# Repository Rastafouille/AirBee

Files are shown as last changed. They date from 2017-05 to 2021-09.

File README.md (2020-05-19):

# AirBee
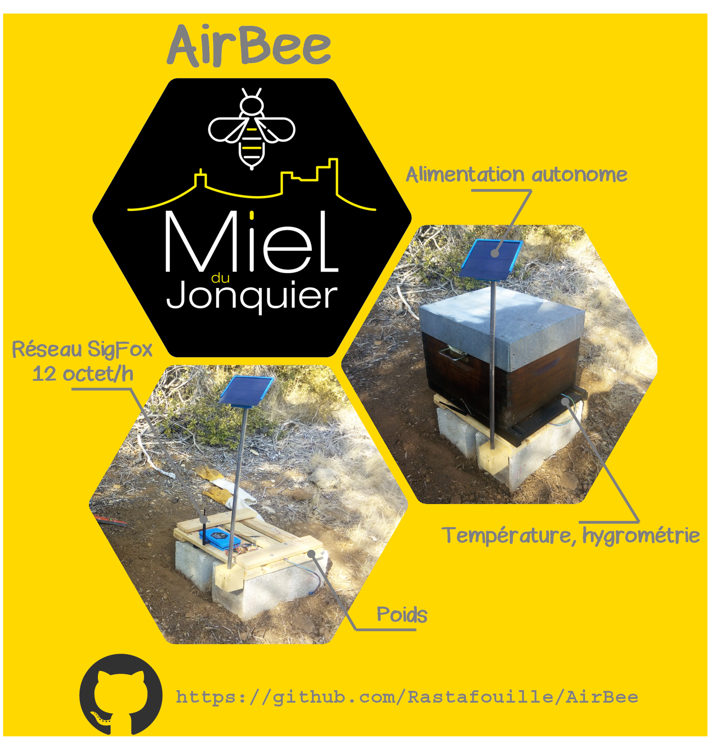
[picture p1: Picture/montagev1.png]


L'idée est de transmettre toutes les données suivantes :
- température dans la ruche -- fait
- humidité dans la ruche -- fait
- masse de la ruche -- fait
- nombre d'abeilles entrées -- pas fait
- nombre d'abeille sortie -- pas fait
- tension de la batterie -- fait
Via un système 100% autonome en énergie et communication

Il y a eu 2 versions v1 et v2, je vous laisse les 2 pour voir ce qui n'a pas/mal fonctionné sur la premiere et les améliorations apportées.

Le système est maintenant abouti et fonctionnel.

## Coté alimentation : 
- Une lipo 5Ah <http://www.cdiscount.com/telephonie/batteries-telephone/easyacc-batterie-externe-5000mah-ultra-slim-charge/f-14487-eas0700686513077.html> (33€)
- Panneau solaire 3W <https://www.digikey.fr/product-detail/fr/seeed-technology-co-ltd/313070001/1597-1414-ND/5488054> (12USD)
- lipoRider <https://www.seeedstudio.com/Lipo-Rider-v1.3-p-2403.html> (9.5USD)

3 fils partent du module d'alim vers la carte (vcc,gnd,Vbat)




Cette partie n'a pas évoluée entre les 2 versions

## Coté intelligence :
- Carte ucontrolleur Arduino nano (2€) <https://fr.aliexpress.com/item/Freeshipping-Nano-3-0-controller-compatible-for-arduino-nano-CH340-USB-driver-NO-CABLE/32242060255.html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>

## Coté communication :
- Kit Carte Breakout Sigfox BRKWS01 + Antenne +fdp TTC + un an abonnement <https://yadom.fr/carte-breakout-sfm10r1.html> (26€)
ou que le module <https://yadom.fr/reseaux-iot/sigfox/pack-10-modules-wisol-sfm10r1-pour-le-reseau-sigfox.html> (4€) mais il faut payer l'abonnement, sauf que l'on ne peut pas en prendre a l'unit", c'est par 10 pour plus de 220€ par an...

## Coté Capteur :
- pour avoir l'heure RTC  <https://www.adafruit.com/product/3296> (7.5USD) -- pas indispensable, supprimé sur la v2.
- Compteur I/O abeilles : projet BeeCounter2 (25USD) <http://www.instructables.com/id/Honey-Bee-Counter-II/> pas fait finalement.
- Capteur température humidité SHT11 (35USD) (2€ sur Aliexpress) <https://www.adafruit.com/product/246>. Une autre version avec DHT22 marche trés bien aussi.
- v1 : Capteur poids X4 + Load Cell Amplifier - HX711 (5€) <https://fr.aliexpress.com/item/FREE-SHIPPING-20pcs-lot-Experiments-body-scale-wholesale-human-scale-load-cell-sensor-resistance-strain-50kg/32271599811.html> et <https://fr.aliexpress.com/item/1PCS-HX711-Weighing-Sensor-Dual-Channel-24-Bit-Precision-A-D-Module-Pressure-Sensor-for-Arduino/32653087154.html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> 
Impossible d'avoir une valeur stable et fiable.... du coup mieux en v2



  v2 : Un seul capteur 100kg + Load Cell Amplifier - HX711, bcp plus précis et sans dérive (17€) <https://fr.aliexpress.com/item/100kg-120kg-parallel-beam-type-load-cell-for-counting-scale-balance-TAL201/32616652058.html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>

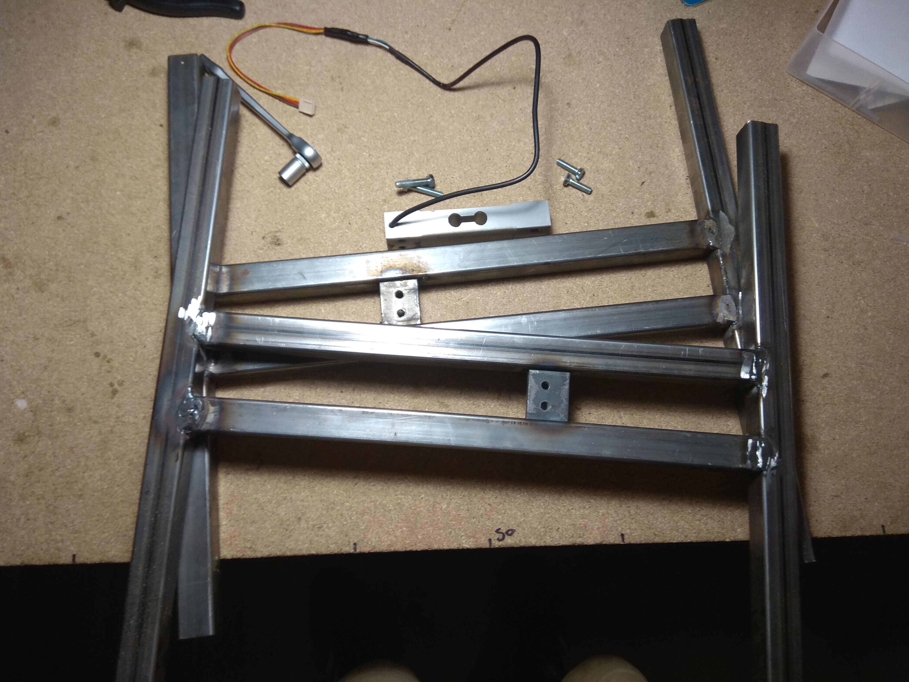
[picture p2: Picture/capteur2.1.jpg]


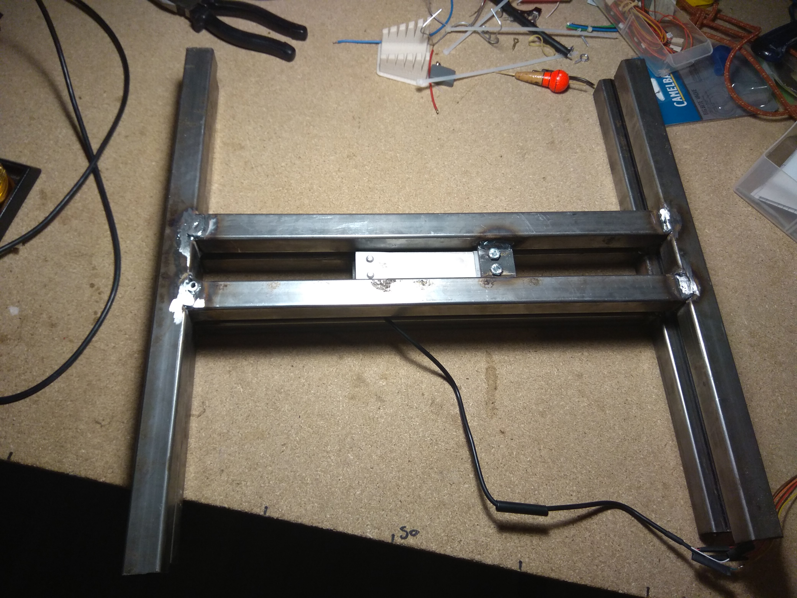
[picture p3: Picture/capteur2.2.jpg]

  
## PCB

- v1
a la main !


- v2

Fait sur Easy EDA <https://easyeda.com/rastafouille/airbeev2-2> fabriqué maison dans un premier temps mais commandé chez jlcpcb ou pcbway pour quelques €

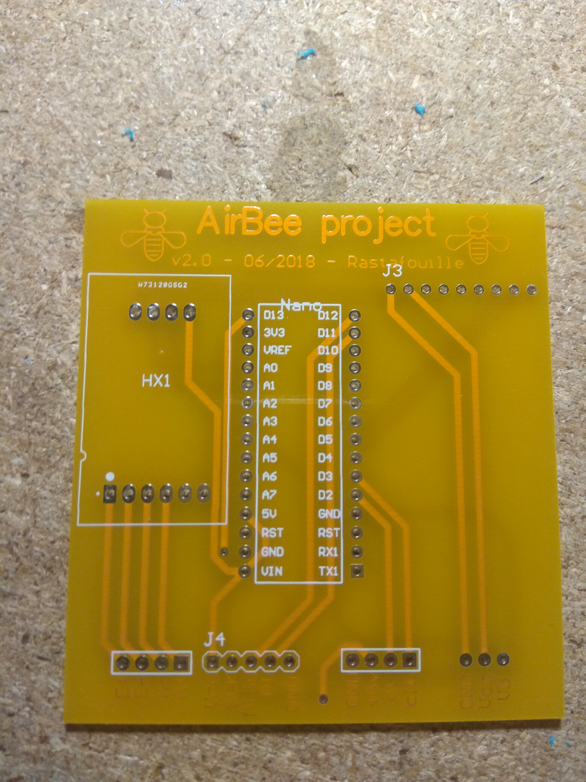
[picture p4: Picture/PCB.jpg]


## Packaging

- Toutes les pièces en impression 3D pour la v1, les fichiers sont dans le dossier CAD. 
pour la v2 seul le module d'alimentation est en 3D print, pour le reste si dessous, bien mieux en finition et étanchéité.

- Connecteurs commandés pour la V2 (8€): <https://www.aliexpress.com/snapshot/0.html?productId=32761320961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>

- Boites commandées pour la V2 (6€): <https://fr.aliexpress.com/item/1-Pc-tanche-Bo-tier-En-Plastique-Bo-te-lectronique-Projet-Instrument-Cas-lectrique-Bo-te/32862281438.html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>

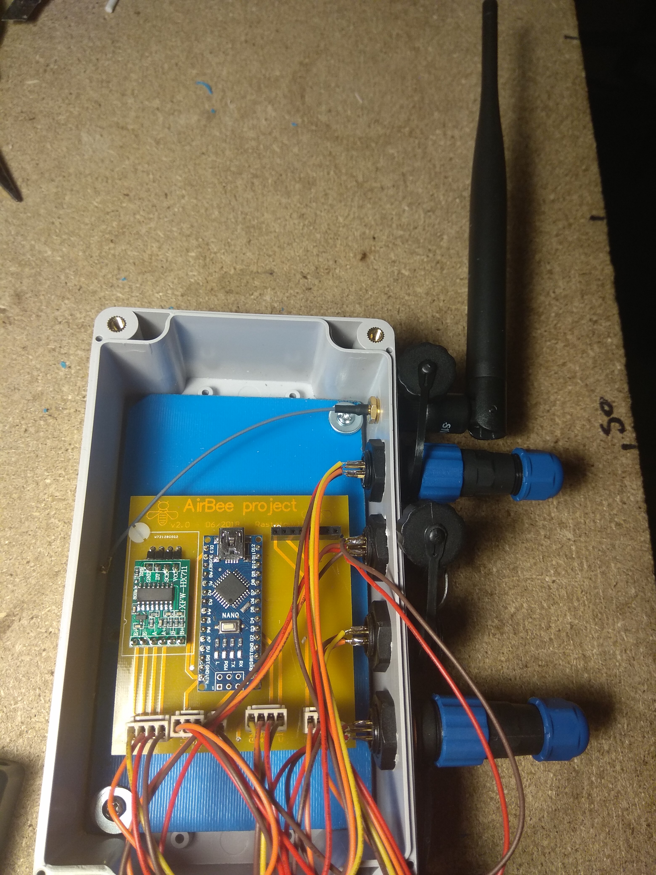
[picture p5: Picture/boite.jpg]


## Vue d'ensemble 

- V1 08/10/2017 



- V2 

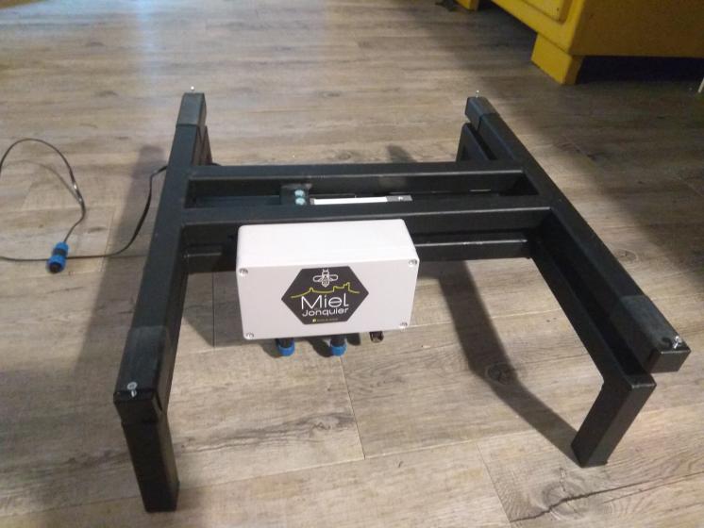
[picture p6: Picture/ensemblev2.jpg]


## Fonctionnement
L'Arduino centralise les données est les envoie au backend sigfox. On a droit à 140 messages de 12 Octets par jour, ca passe juste sans optimisation.

Payload : 
	
	ID::uint:8 Temp::int:16:little-endian Hum::uint:16:little-endian Poids::uint:16:little-endian IN::uint:16:little-endian OUT::uint:16:little-endian Vbat::uint:8

Sigfox renvoie les données via des CallBacks vers serveur perso (php-->json) et backend web (app.we-sens.com). je n'ai rien fait coté web j'utilise le site hebergeur d'un copain (app.we-sens.com) qui m'affiche les données.

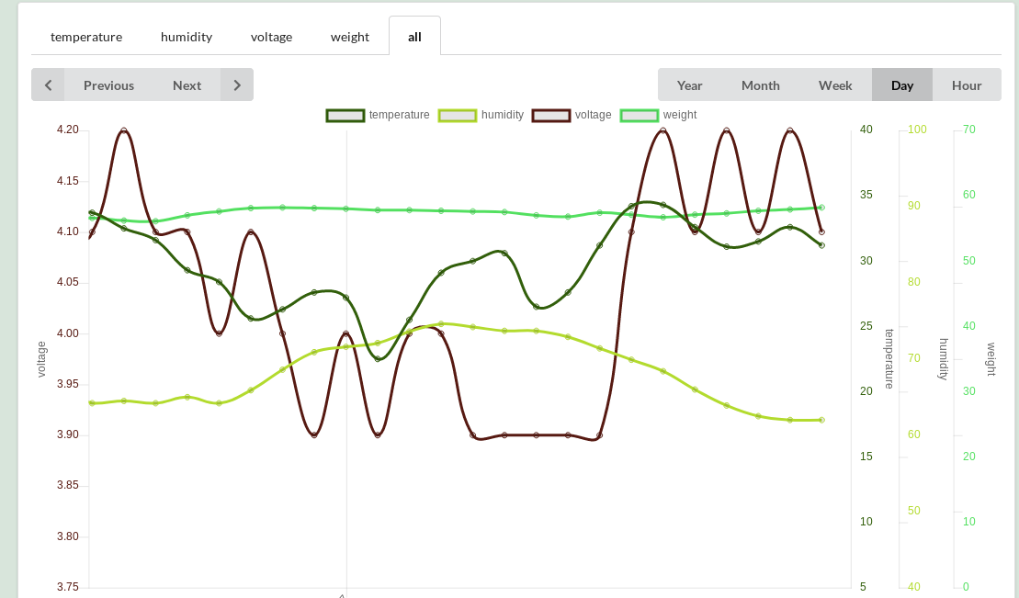
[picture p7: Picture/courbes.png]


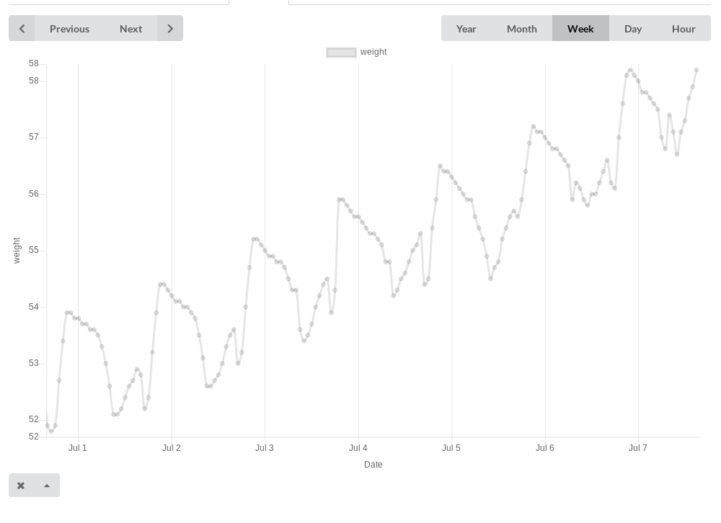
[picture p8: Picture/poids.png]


# Release
- v2 : suppression du RTC / changement capteur de poids et plateau / carte electronique dédiée faite maison

- V2.1: boite / connecteur / PCB pro / rafraichissement toutes les 15 min

- V2.2 04/2020 : soudage pieds au plateau / DHT22 car SHT11 plus dispo / module sigfox en 3.3v / passage de circuit maker à easyEDA

# Perspectives
- Rajouter le compteur d'abeilles

- Rajouter une station météo mais les données capteurs humudité+température+tension batterie (ensoleillement) peuvent suffires.

- Peut etre créer un reseau Xbee local sur 5 ruches pour un seul module Sigfox (si utile d'avoir plusieurs ruches connectées dans le même rucher?)

- optimiser l'energie pour passer en pile lithium 3.3V et se passer du panneau solaire.

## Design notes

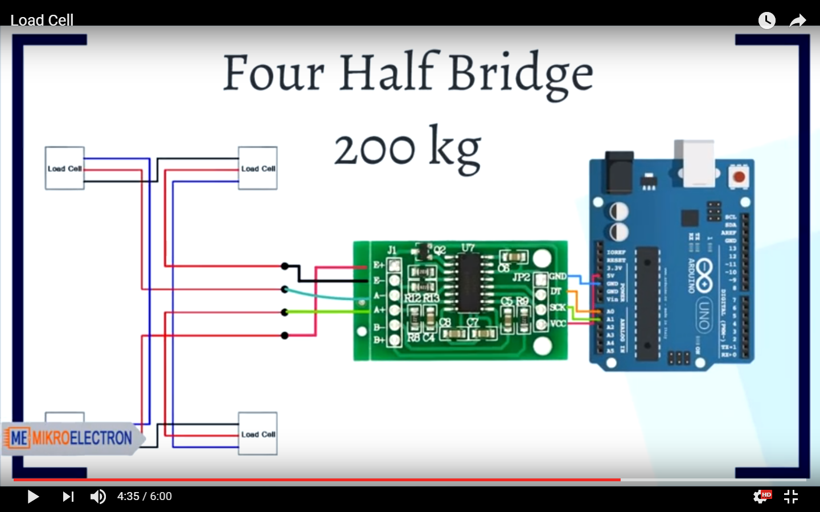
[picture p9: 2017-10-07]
vrac/loadcell.png

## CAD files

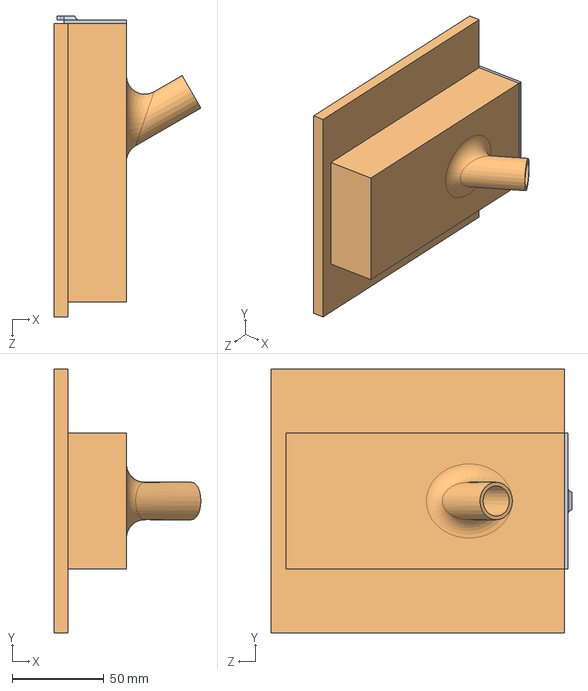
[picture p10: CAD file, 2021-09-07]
CAD/Assemblage1.SLDASM
80.1 x 144.0 x 164.0 mm
boitier_solaire_couv_v2
boitier_solaire_v2

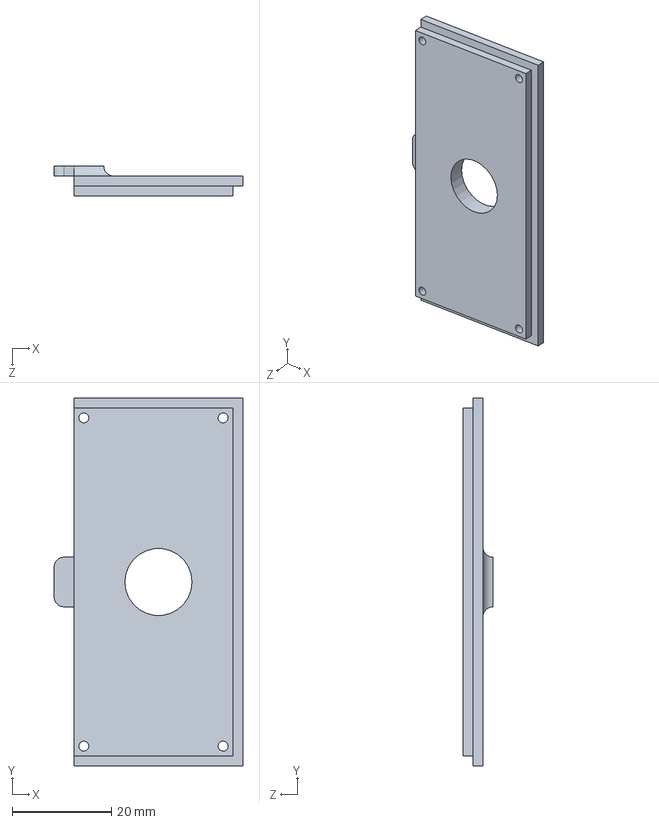
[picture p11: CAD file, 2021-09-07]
CAD/boitier_solaire_couv_v2.SLDPRT
38.0 x 74.0 x 6.00 mm

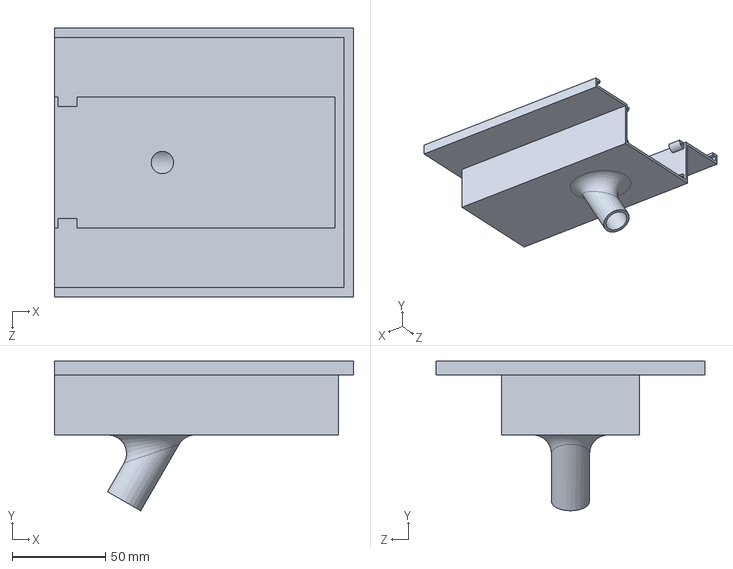
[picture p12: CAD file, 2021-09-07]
CAD/boitier_solaire_v2.SLDPRT
160.0 x 80.1 x 144.0 mm

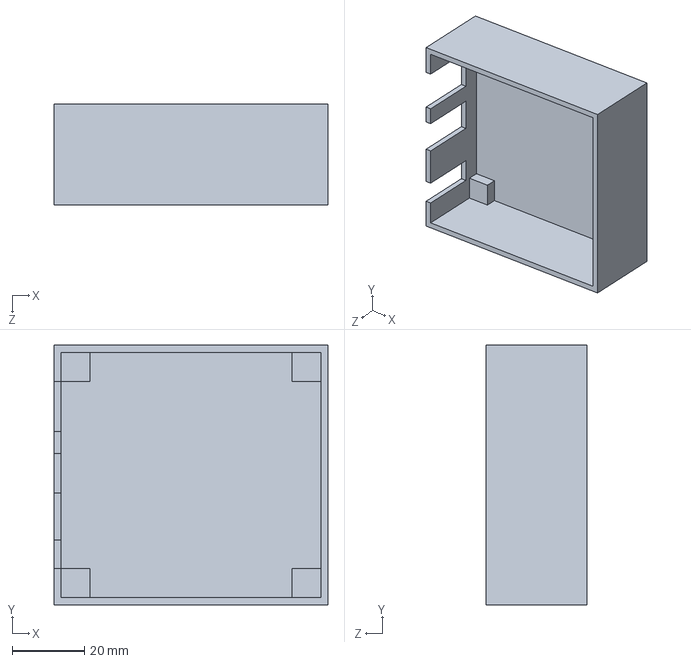
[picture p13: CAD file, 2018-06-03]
CAD/boite_electV2.SLDPRT
76.0 x 72.0 x 28.0 mm

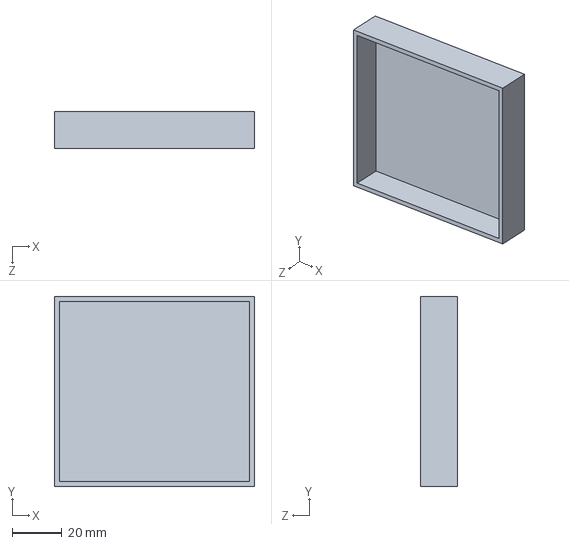
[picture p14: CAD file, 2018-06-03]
CAD/boite_elect_couvV2.SLDPRT
80.5 x 76.5 x 15.0 mm

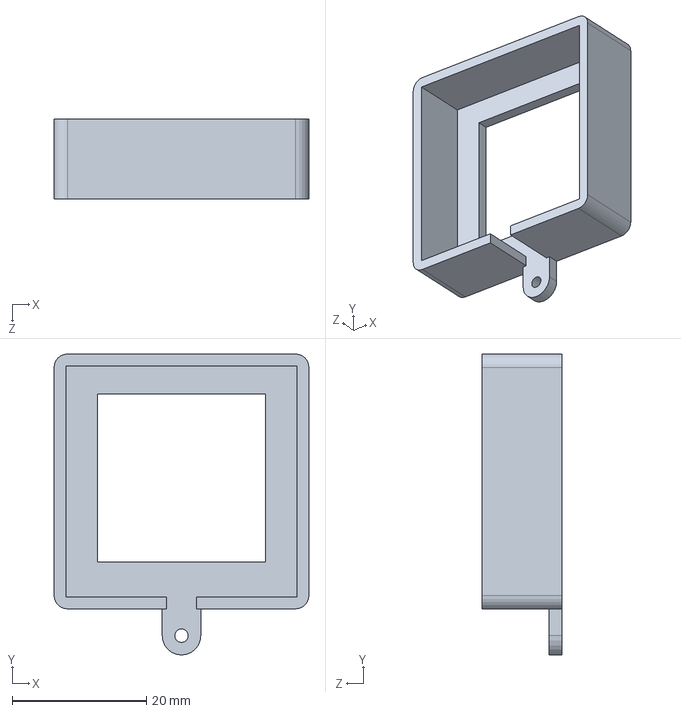
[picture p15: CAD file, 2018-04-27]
CAD/base _load.SLDPRT
38.0 x 44.9 x 12.0 mm

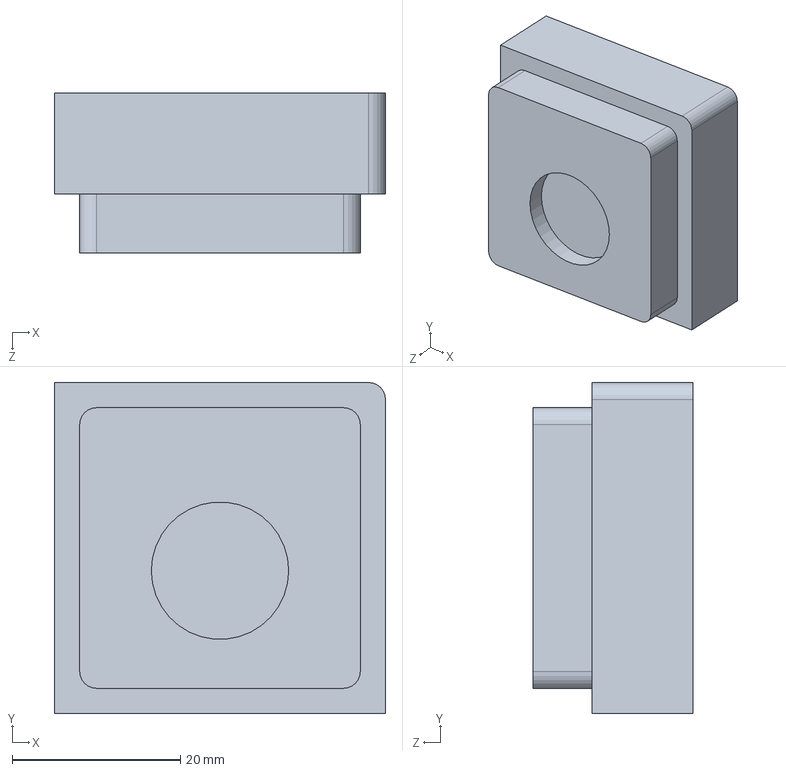
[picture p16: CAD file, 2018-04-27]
CAD/capot_load.SLDPRT
39.4 x 39.4 x 19.0 mm

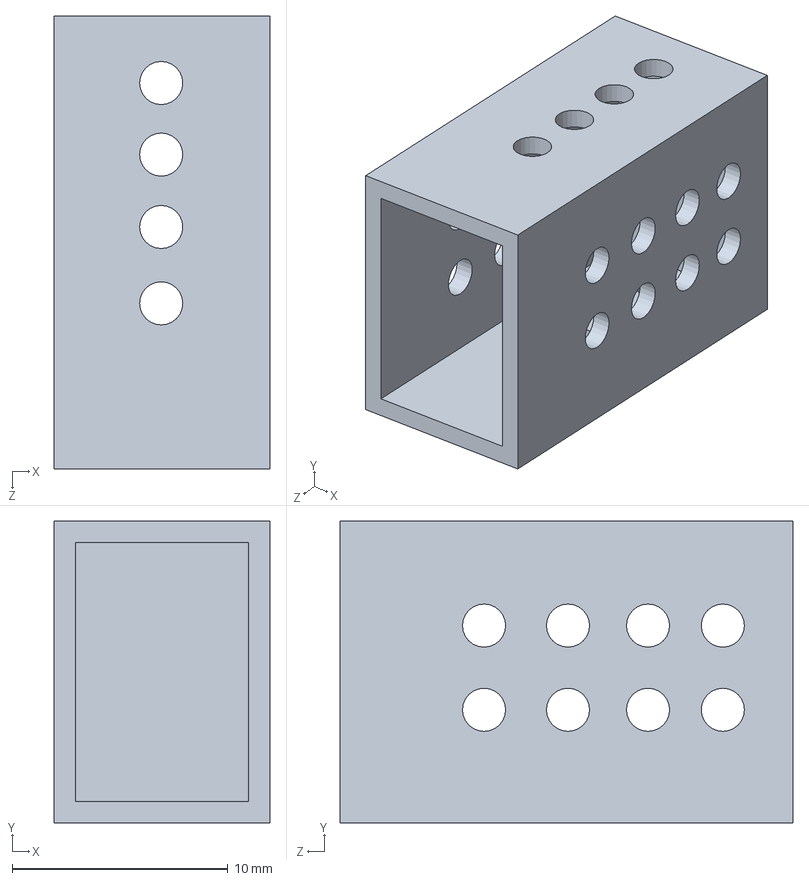
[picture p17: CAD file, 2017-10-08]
CAD/boite_temp.SLDPRT
10.0 x 14.0 x 21.0 mm

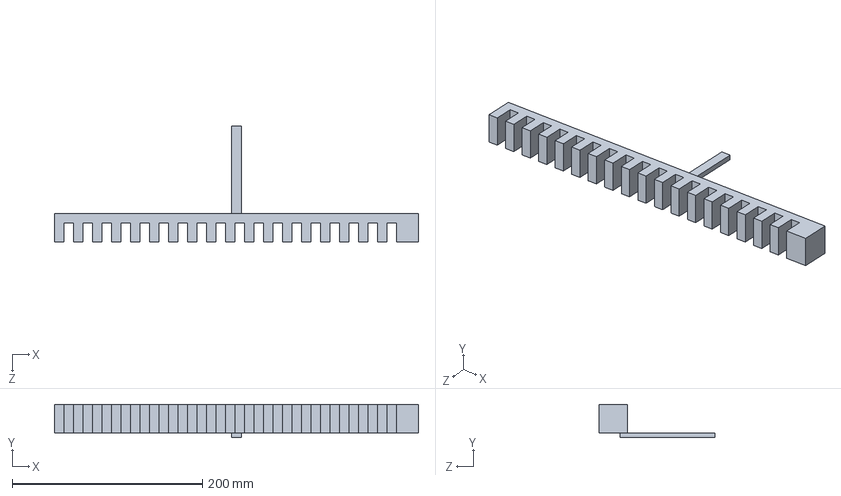
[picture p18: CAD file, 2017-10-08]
CAD/Porte.SLDPRT
383.0 x 35.0 x 121.8 mm

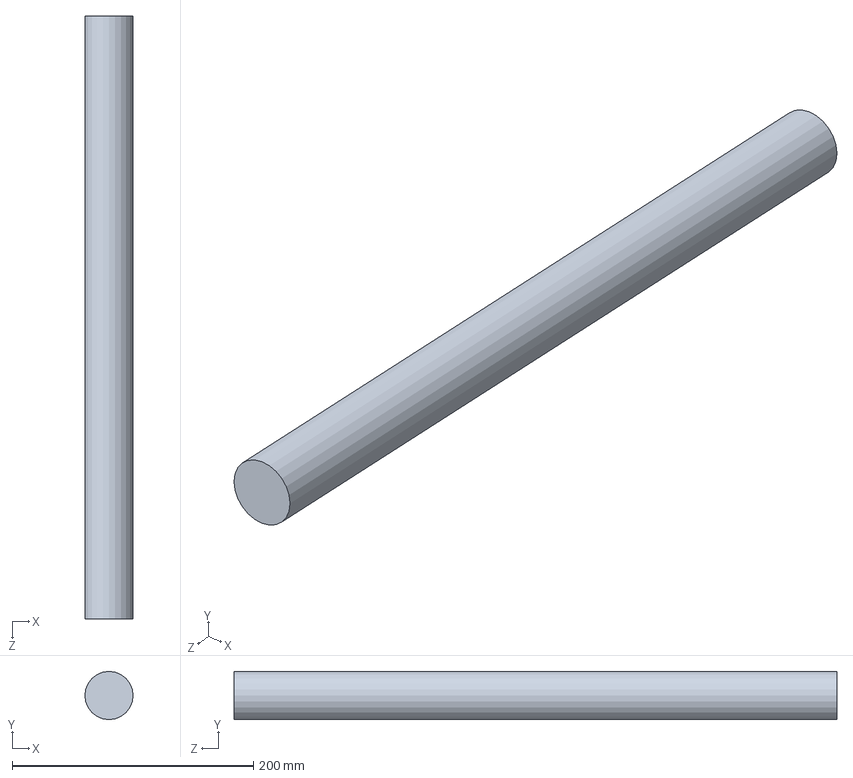
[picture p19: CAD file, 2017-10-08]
CAD/boitier_solaire_tube.SLDPRT
40.0 x 40.0 x 500.0 mm

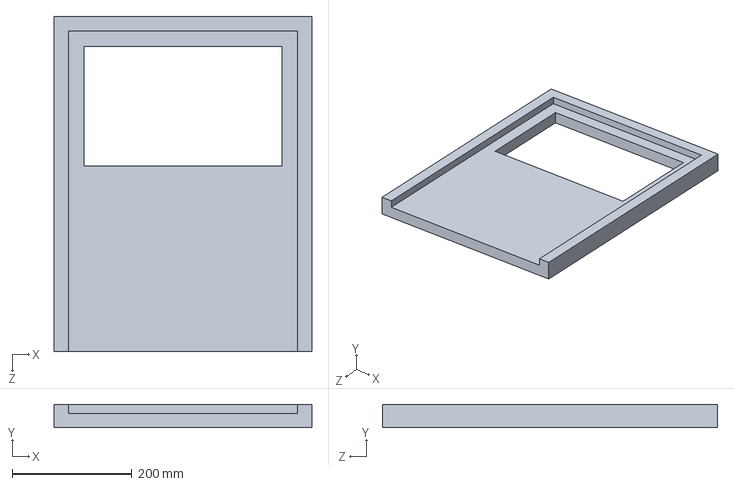
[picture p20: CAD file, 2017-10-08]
CAD/PlateauDadant.SLDPRT
431.0 x 39.0 x 560.0 mm

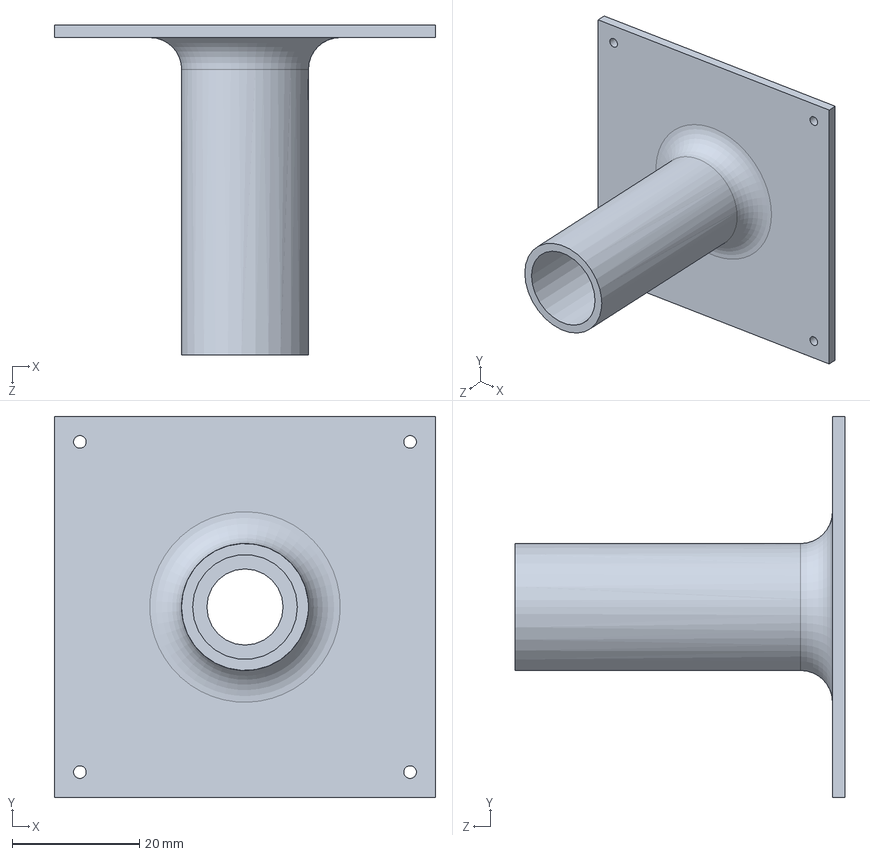
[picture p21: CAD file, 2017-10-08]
CAD/boitier_solaire_support.SLDPRT
60.0 x 60.0 x 52.0 mm

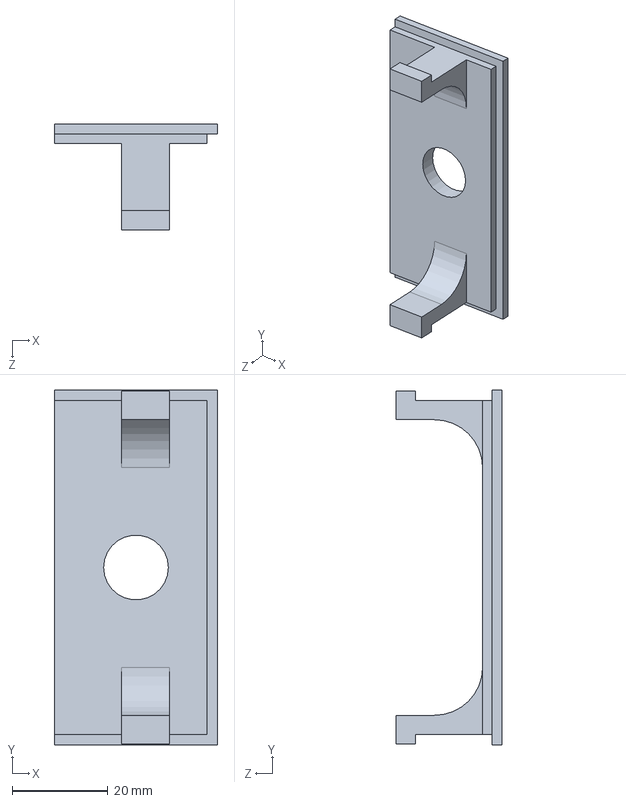
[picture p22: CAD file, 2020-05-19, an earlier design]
CAD/boitier_solaire_couv.SLDPRT
34.0 x 74.0 x 22.0 mm

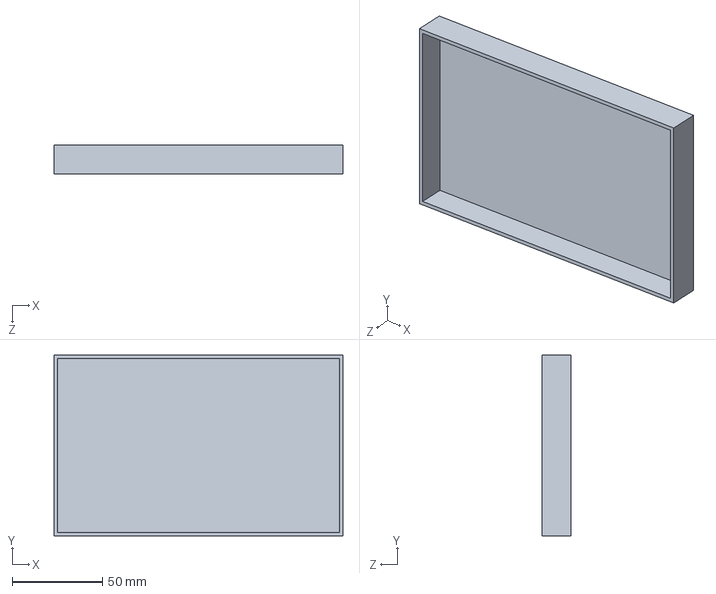
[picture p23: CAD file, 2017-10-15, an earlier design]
CAD/boite_elect_couv.SLDPRT
160.5 x 100.5 x 16.0 mm

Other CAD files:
CAD/boitier_solaire.SLDPRT
CAD/boite_elect.SLDPRT
CAD/base _load.STL
CAD/boite_elect.STL
CAD/boite_electV2.STL
CAD/boite_elect_couv.STL
CAD/boite_elect_couvV2.STL
CAD/boite_temp.STL
CAD/boitier_solaire.STL
CAD/boitier_solaire_couv.STL
CAD/boitier_solaire_couv_v2.STL
CAD/boitier_solaire_support.STL
CAD/boitier_solaire_v2.STL

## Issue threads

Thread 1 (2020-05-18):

echange sur le projet

guigui91, 2020-05-18:
Super votre projet. Ou peut on echanger avec vous?

Rastafouille, 2020-05-18:
bonjour, bien-sûr avec plaisir.

guigui91, 2020-05-18:
avez vous un email ou par ce biais la?

Rastafouille, 2020-05-18:
sur gît c'est très bien, que voulez vs savoir?

guigui91, 2020-05-18:
je me lance dans l'apiculture, je viens d'acheter deux ruches et votre projet me parait vraiement tres bien. j'ai bien compris la partie alimentation avec le panneau solaire la batterie et le module de chargement. Pour la partie de la balance vous avez un capteur et un amplificateur. Je repere bien sur le schema l'amplificateur ainsi que le nano par contre je ne vois pas le capteur d'humidité et temperature sht11 (d'ailleurs il n'a plus l'air d'exister en vente) ou est il branché? l'arrive du courant doit se faire dans un des connecteurs etanches mais a quoi servent les 3 autres?

Rastafouille, 2020-05-19:
Bonjour, le sht11 est branché sur l'arduino, je vais mettre le schéma a jour directement sur Git dans la semaine ce sera plus facile. pour les connecteurs il y a lalim, le capteur humidité température, le compteur d'abeilles (pas utilisé) et le capteur de poids.

Rastafouille, 2020-05-19:
si plus de sht11 on peut utiliser un DHT22, jai le code a jour pour ce capteur,
https://fr.aliexpress.com/item/32884816378.html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,searchweb201602_,searchweb201603_

guigui91, 2020-05-19:
ok j'utilise ce capteur aussi dans un autre projet et donc c'est ce capteur entre autre qui est dans un des connecteurs etanches? le plastique ne gene pas dans le calcul?

Rastafouille, 2020-05-19:
le capteur est a lextérieur au bout d'un cable pour le mettre ou on veut, avant je mettais dans la ruche mais ca ne m'apportait rien donc maintenant je ne mets dessous. Du coup il est relié a l'arduino via un connecteur étanche. le calcul de quoi? l'arduino interroge le capteur qui lui donne la température et l'humidité, il n'y a rien a calculer.

Rastafouille, 2020-05-19:
dans le schema que tu as, il y a une erreur, le module sigfox doit etre alimenté en 3.3v pas en 5.5v du coup il faut rajouter un pont diviseur avec 2 resistances.

Rastafouille, 2020-05-19:
jai mis a jour le schema

guigui91, 2020-05-19:
bon il faut que je commande tout lol ali express ils sont pas pressé lol

guigui91, 2020-05-19:
je pensais qu'on ne pouvis pas mettre le capteur a l'exterieur je pensais pas qu'il resistait au intemperies, du coup il donne la temperature  en dessous la ruche?la capteur de poids il ne depasse pas du support je ne vois pas le capteur de poids sur le support

Rastafouille, 2020-05-20:
j'ai des pièces en rabe, tu habites où?

Rastafouille, 2020-05-20:
il est au bout d'un fil tu le mets où tu veux

guigui91, 2020-05-20:
region parsienne

guigui91, 2020-05-20:
et vous

Rastafouille, 2020-05-24:
bonjour, pardon, pas spécialement dispo, je regarde ce que j'ai, je dois avoir des pcb, hx711 en rabe.

guigui91, 2020-05-25:
vous etes d'ou?

Rastafouille, 2020-05-25:
Avignon

guigui91, 2020-10-24:
hello je me remet sur ce projet. Tu aurais les dimensions du support stp ?

Rastafouille, 2020-11-04:
Bonjour, désolé jai tardé a répondre, je n'ai pas de plan... et il faut surtout l'adapter a ton format de ruches.

guigui91, 2020-11-04:
je suis en ruche dadant

freeflyer11, 2023-05-11:
Bonjour, super projet, quel est le bilan après plusieurs mois en fonctionnement ?

freeflyer11, 2023-05-11:
Comment faire réaliser la carte pcb  PCB chez  Easy EDA, à paritr de quel fichier ?
merci

Rastafouille, 2023-05-11:
Bonjour,
ca fonctionne depuis des années, ca marche vraiment bien !
J'ai des fois des soucis avec les batteries que je ne sais trop expliquer...
Pour le pcb j'avais un peu galéré à fournir le bon fichier à PCBWay, ce n'est pas ma spécialité, après échange avec eux ils m'ont expliqué. Il faut le fichier gerber. Par contre je n'ai pas touché à EasyEDA depuis donc je ne m'en souviens plus...

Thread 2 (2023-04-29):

prise en charge des loadcell grande capacité

buched, 2023-04-29:
Bonjour, avec le code, la valeur en gramme est limitée a 65635 ( a peu pres), pour ne plus avoir cette limitation, il faut modifier uint16_t en uint32_t pour le payload weight a 2 endroits dans l'ino et aussi modifier le callback dans le backend sigfox
`//TIME https://github.com/PaulStoffregen/Time
#include <TimeLib.h>
int tempo = 92;
int PERIODE =90;
int chrono = 99;

//WEIGHT https://github.com/bogde/HX711
#include "HX711.h"
HX711 scale;
float final;
float inter;

//SLEEP MODE http://donalmorrissey.blogspot.fr/2010/04/sleeping-arduino-part-5-wake-up-via.html
#include <avr/sleep.h>
#include <avr/power.h>
#include <avr/wdt.h>
volatile int f_wdt=1;

//DHT humidity/temperature sensors

// REQUIRES the following Arduino libraries:
// - DHT Sensor Library: https://github.com/adafruit/DHT-sensor-library
// - Adafruit Unified Sensor Lib: https://github.com/adafruit/Adafruit_Sensor
#include "DHT.h"
#define DHTPIN 2
#define DHTTYPE DHT22
DHT dht(DHTPIN, DHTTYPE);

// connexion serie pour Sigfox
  #include <SoftwareSerial.h>
  SoftwareSerial SigFox(4,5); // RX, TX

//définition des variable pour le payload SF
  typedef struct  {
    uint8_t id;
    int16_t temperature;
    uint16_t humidity;
    uint32_t weight;
    uint8_t vbat;
  } rowPayload_s;

  union payload_u
  {
    rowPayload_s data;
    uint8_t rawData[sizeof(rowPayload_s)];
  } payload;

//
void setup()
{
  pinMode(13, OUTPUT);

  dht.begin();

  if (DEBUG)
  { Serial.begin(9600);Serial.println("Starting up"); delay(100);}
  SigFox.begin(9600);
  if (DEBUG){print_date();  }

 /*** Setup the WDT ***/
  /* Clear the reset flag. */
  MCUSR &= ~(1<<WDRF);
  /* In order to change WDE or the prescaler, we need to set WDCE (This will allow updates for 4 clock cycles).*/
  WDTCSR |= (1<<WDCE) | (1<<WDE);
  /* set new watchdog timeout prescaler value */
  WDTCSR = 1<<WDP0 | 1<<WDP3; /* 8.0 seconds */
  /* Enable the WD interrupt (note no reset). */
  WDTCSR |= _BV(WDIE);

  // WEIGHT
  // parameter "gain" is ommited; the default value 128 is used by the library
  // HX711.DOUT	- pin #A1
  // HX711.PD_SCK	- pin #A0
  scale.begin(A1, A0);
  scale.set_scale(460.757);
  scale.tare();

  chrono=minute();
  pinMode(LED_BUILTIN, OUTPUT);
  digitalWrite(LED_BUILTIN, HIGH);   // turn the LED on (HIGH is the voltage level)
  delay(1000);                       // wait for a second
  digitalWrite(LED_BUILTIN, LOW);    // turn the LED off by making the voltage LOW
  delay(1000);                       // wait for a second
}

void loop()
{

if(f_wdt == 1)
  {
      if (chrono!=minute())
        {
          chrono =minute(); tempo ++;
          if (DEBUG) {Serial.print("tempo: ");Serial.println (tempo);}
        }
      if (tempo >= PERIODE)
        {
          tempo=0;
          payload.data.id=139;//idx du capteur virtuel dans domoticz
          payload.data.temperature = int16_t (dht.readTemperature()*10);
          payload.data.humidity = int16_t (dht.readHumidity()*10);
          payload.data.weight=int32_t (getweight()*10);
          payload.data.vbat= int(analogRead(A3) * (37 / 1023.0));
            delay(500);

          // On balance
            envoieSF();
        }

    /* Don't forget to clear the flag. */
    f_wdt = 0;

    /* Re-enter sleep mode. */
    enterSleep();
  }
}

void print_date ()
{
    Serial.print(hour(), DEC);Serial.print(':');
    Serial.print(minute(), DEC);Serial.print(':');
    Serial.print(second(), DEC);Serial.println();
}

void envoieSF()
{
  if (DEBUG) {Serial.println("ENVOIE SF...");}
  SigFox.print("AT$SF=");
  for (byte i = 0; i < sizeof(payload); i++)
  {
    if (payload.rawData[i] <= 0xF) SigFox.print("0"); // pour bien avoir 2 caractères
    SigFox.print(payload.rawData[i], HEX);
  }
  SigFox.print("\r");
  if (DEBUG) {Serial.println("ENVOIE SF OK !"); }
 }

ISR(WDT_vect)
{
  if(f_wdt == 0){f_wdt=1;}
  //else  {Serial.println("WDT Overrun!!!");}
}

void enterSleep(void)
{
  set_sleep_mode(SLEEP_MODE_PWR_SAVE);
  sleep_enable();delay(100);

  /* Now enter sleep mode. */
    if (DEBUG) {print_date();Serial.println("SLEEP Mode activated");}
    delay(100);
  sleep_mode();

    /* The program will continue from here after the WDT timeout*/
  sleep_disable(); /* First thing to do is disable sleep. */

  /* Re-enable the peripherals. */
  power_all_enable();delay(100);
  setTime(hour(),minute(),second()+8,day(),month(),year());
  if (DEBUG) {print_date();Serial.println("SLEEP Mode disactivated");}
 }

float getweight(void)
{
  scale.power_up();
  final=scale.get_units(10), 1;
  Serial.println(final);
  scale.power_down();			        // put the ADC in sleep mode
  return final;
}`

exemple avec ton code modifié pour mes besoins

Rastafouille, 2023-04-29:
Bonjour,
j'envoie en centaine des grammes du coup je suis large

buched, 2023-07-21:
> Bonjour, j'envoie en centaine des grammes du coup je suis large

pourtant avec le code d'origine, quand ma ruche dépasse les 65635 grammes, ca repasse a 0

Rastafouille, 2023-07-27:
Salut,
oui dés que tu dépasses 65635 ca redémarre a zéro, normal, divise tout par 10 ou 100.

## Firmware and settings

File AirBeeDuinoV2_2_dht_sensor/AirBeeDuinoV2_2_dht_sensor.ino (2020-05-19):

//TIME https://github.com/PaulStoffregen/Time
#include <TimeLib.h>
int tempo = 15;
int PERIODE =12;
int chrono = 99;

//activation du Serial pour le debug
byte DEBUG = false;

//WEIGHT https://github.com/bogde/HX711
#include "HX711.h"
HX711 scale;
float final;
float inter;


//SLEEP MODE http://donalmorrissey.blogspot.fr/2010/04/sleeping-arduino-part-5-wake-up-via.html
#include <avr/sleep.h>
#include <avr/power.h>
#include <avr/wdt.h>
volatile int f_wdt=1;


//DHT humidity/temperature sensors

// REQUIRES the following Arduino libraries:
// - DHT Sensor Library: https://github.com/adafruit/DHT-sensor-library
// - Adafruit Unified Sensor Lib: https://github.com/adafruit/Adafruit_Sensor
#include "DHT.h"
#define DHTPIN 2
#define DHTTYPE DHT22 
DHT dht(DHTPIN, DHTTYPE);

// connexion serie pour Sigfox
  #include <SoftwareSerial.h>
  SoftwareSerial SigFox(4,5); // RX, TX

//définition des variable pour le payload SF
  typedef struct  {
    uint8_t id;
    int16_t temperature;
    uint16_t humidity;
    uint16_t weight; 
    uint16_t bee_in; 
    uint16_t bee_out; 
    uint8_t vbat; 
  } rowPayload_s;

  union payload_u
  {
    rowPayload_s data;
    uint8_t rawData[sizeof(rowPayload_s)];
  } payload;

//
void setup()
{
  pinMode(13, OUTPUT);

  dht.begin();
  
  if (DEBUG) 
  { Serial.begin(9600);Serial.println("Starting up"); delay(100);}
  SigFox.begin(9600);
  if (DEBUG){print_date();  }
  
 /*** Setup the WDT ***/
  /* Clear the reset flag. */
  MCUSR &= ~(1<<WDRF);
  /* In order to change WDE or the prescaler, we need to set WDCE (This will allow updates for 4 clock cycles).*/
  WDTCSR |= (1<<WDCE) | (1<<WDE);
  /* set new watchdog timeout prescaler value */
  WDTCSR = 1<<WDP0 | 1<<WDP3; /* 8.0 seconds */
  /* Enable the WD interrupt (note no reset). */
  WDTCSR |= _BV(WDIE);
  
  // WEIGHT
  // parameter "gain" is ommited; the default value 128 is used by the library
  // HX711.DOUT	- pin #A1
  // HX711.PD_SCK	- pin #A0
  scale.begin(A1, A0);
  //scale.set_scale();
  scale.tare();
  
  chrono=minute();
  pinMode(LED_BUILTIN, OUTPUT);
  digitalWrite(LED_BUILTIN, HIGH);   // turn the LED on (HIGH is the voltage level)
  delay(1000);                       // wait for a second
  digitalWrite(LED_BUILTIN, LOW);    // turn the LED off by making the voltage LOW
  delay(1000);                       // wait for a second
}

void loop()
{
  
if(f_wdt == 1)
  {
      if (chrono!=minute()) 
        {
          chrono =minute(); tempo ++;
          if (DEBUG) {Serial.print("tempo: ");Serial.println (tempo);}  
        }
      if (tempo >= PERIODE)
        { 
          tempo=0;
        //    if (DEBUG) {Serial.print("tempo: ");Serial.println (tempo);}
          // on charge les valeurs
    
          payload.data.id=1;
          payload.data.temperature = int16_t (dht.readTemperature()*10);
          payload.data.humidity = int16_t (dht.readHumidity()*10);
          payload.data.weight=int16_t (getweight()*10);
          payload.data.bee_in=0;
          payload.data.bee_out=0;
          payload.data.vbat= int(analogRead(A3) * (50 / 1023.0));
            delay(500);
          //on affiche
              if (DEBUG) {print_payload();}
          
          // On balance
            envoieSF();
        }
       
    /* Don't forget to clear the flag. */
    f_wdt = 0;
    
    /* Re-enter sleep mode. */
    enterSleep();
  }
}
  
void print_date () 
{
    Serial.print(hour(), DEC);Serial.print(':');
    Serial.print(minute(), DEC);Serial.print(':');
    Serial.print(second(), DEC);Serial.println();
}

void envoieSF() 
{   
  if (DEBUG) {Serial.println("ENVOIE SF...");}
  SigFox.print("AT$SF=");
  for (byte i = 0; i < sizeof(payload); i++) 
  {
    if (payload.rawData[i] <= 0xF) SigFox.print("0"); // pour bien avoir 2 caractères
    SigFox.print(payload.rawData[i], HEX);
  }
  SigFox.print("\r");
  if (DEBUG) {Serial.println("ENVOIE SF OK !"); }
 }

void print_payload()
{ 
  Serial.println("-----PAYLOAD-----");
  Serial.print("ID:");Serial.println(payload.data.id);
  Serial.print("Temperature: ");Serial.print(float (payload.data.temperature)/10,1);Serial.println(" C");
  Serial.print("Humidity: "); Serial.print(float(payload.data.humidity)/10,1);Serial.println(" %");
  Serial.print("Poids:");Serial.print(float(payload.data.weight)/10,1);Serial.println(" kg");
  Serial.print("Bee IN:");Serial.println(payload.data.bee_in);
  Serial.print("Bee OUT:");Serial.println(payload.data.bee_out);
  Serial.print("Vbat:");Serial.print(float(payload.data.vbat)/10,1);Serial.println(" Volt");
  Serial.println("-----------------");
}

ISR(WDT_vect)
{
  if(f_wdt == 0){f_wdt=1;}
  //else  {Serial.println("WDT Overrun!!!");}
}


void enterSleep(void)
{
  set_sleep_mode(SLEEP_MODE_PWR_SAVE);   
  sleep_enable();delay(100);
  
  /* Now enter sleep mode. */
    if (DEBUG) {print_date();Serial.println("SLEEP Mode activated");}
    delay(100);
  sleep_mode();
  
    /* The program will continue from here after the WDT timeout*/
  sleep_disable(); /* First thing to do is disable sleep. */
  
  /* Re-enable the peripherals. */
  power_all_enable();delay(100);
  setTime(hour(),minute(),second()+8,day(),month(),year());
  if (DEBUG) {print_date();Serial.println("SLEEP Mode disactivated");}
 }

float getweight(void)
{
  scale.power_up();
  final=scale.get_value(10)/36300;//(44250v1 et 36300v2)
  scale.power_down();			        // put the ADC in sleep mode
  return final;
}

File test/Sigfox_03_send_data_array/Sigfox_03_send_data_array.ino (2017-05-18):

//#include <Wire.h>
//
//// Cooking API libraries
//#include <arduinoUART.h>
//#include <arduinoUtils.h>
//
//// Sigfox library
//#include <arduinoSigfox.h>
//
////////////////////////////////////////////////
//uint8_t socket = SOCKET0;     //Asign to UART0
////////////////////////////////////////////////
//
//unsigned long pausetime = 30000;  // pause in ms
//unsigned long previousMillis = 0; 

#include <SoftwareSerial.h>
SoftwareSerial SigFox(4,5); // RX, TX

// define variable to create a speficic frame to be sent
uint8_t data[12];

// define union-type variables
union
{
  String AT="AT$SF=";
  uint8_t id=1;
  int16_t temperature=-126;
  uint16_t humidity=563;
  uint16_t poids=1257;
  uint16_t in=2569;
  uint16_t out=5149;
  uint8_t vbat=51;
}data_union;

int size=sizeof(data_union.AT)+12;
Serial.println(size);


void setup() 
{
  
    Serial.begin(9600); // Open serial connection to report values to host
  Serial.println("Starting up");
       SigFox.begin(9600);

}


void loop() 
{
  
//        data[0] = id; // big-endian
//        data[1] = highByte(temperature);
//        data[2] = lowByte(temperature);
//        data[3] = highByte(humidity);
//        data[4] =lowByte(humidity);
//        data[5] = highByte(poids);
//        data[6] = lowByte(poids);
//        data[7] =highByte(in);
//        data[8] = lowByte(in);
//        data[9] = highByte(out);
//        data[10] =lowByte(out);
//        data[11] = vbat;
        
  String str = (char*)data_union;
  String str2 =String(String("AT$SF=")+ String(data));
        
  SigFox.write(String("AT$SF=")+String("11"));
  //SigFox.println(str);


  digitalWrite(13, HIGH);   // turn the LED on (HIGH is the voltage level)
  delay(1000);              // wait for a second
  digitalWrite(13, LOW);    // turn the LED off by making the voltage LOW
  delay(1000000); 


    
//    //////////////////////////////////////////////
//    // 2. create array with sensor data
//    // Sigfox Back-END device "Display type" must be: 
//    // Temp::float:32 Battery::uint:8 Digital8::bool:7 Digital7::bool:6
//    //       Digital6::bool:5 Digital5::bool:4 Digital4::bool:3
//    //       Digital3::bool:2 Digital2::bool:1 Digital1::bool:0
//    //////////////////////////////////////////////
//  
//    // 2. Reading sensors:
////    data_union.id =1
////    data_union.temperature = -106;
////    data_union.humidity = 523;
////    data_union.poids = 527;
////    data_union.in = 5695;
////    data_union.out = 3287;
////    data_union.vbat = 32;
//  
//    // 2.4. Fill structure fields
//    temp_union.value2 = temperature;  
//  
//    // fill 'data' buffer with data
//    data[0] = temp_union.value1[3]; // big-endian
//    data[1] = temp_union.value1[2];
//    data[2] = temp_union.value1[1];
//    data[3] = temp_union.value1[0];
//    data[4] = battery;
//    data[5] = digitalPins;
//    size = 6;
//         
//    //Final Frame to send in "data"
//  
//    //////////////////////////////////////////////
//    // 3. send data
//    //////////////////////////////////////////////
//   
//    //3. Sending packet:
//    error = Sigfox.send(data,size);
//  
//    // Check sending status
//    if( error == 0 ) 
//    {
//      //"Sigfox packet sent OK"
//      digitalWrite(error_led, LOW);     
//    }
//    else 
//    {
//      //"Sigfox packet sent ERROR" 
//      digitalWrite(error_led, HIGH);
//    } 
//  }
  //////////////////////////////////////////////
  // 4. sleep pause_time (minutes)
  //////////////////////////////////////////////
}

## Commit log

2017-05-18 ajout test/ et mise ajour toutes les heures
2017-10-08 ajout photos et 3D
    [boitier_solaire.STL, boitier_solaire_couv.STL, boitier_solaire_support.STL]
2017-10-08 maj CAD
    [Assemblage1.SLDASM, PlateauDadant.SLDPRT, Porte.SLDPRT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]
2017-10-08 cad boite temperature
    [boite_temp.SLDPRT, boite_temp.STL]
2017-10-10 ajout CAD elect couv
    [boite_elect_couv.SLDPRT, boite_elect_couv.STL]
2017-10-10 add PCB
    [AirBee.sch, Nano.sch]
2017-10-10 maj pcb
    [AirBee.sch, Nano.sch]
2017-10-15 rallonge couvercle
    [boite_elect_couv.SLDPRT, boite_elect_couv.STL]
2017-10-15 debug arduino+tare au demarrage
2017-10-18 maj arduino et readme
2018-06-03 v2
    v2
    [boite_electV2.SLDPRT, boite_electV2.STL, boite_elect_couvV2.SLDPRT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]
2021-09-07 update cad boitier solaire
    [Assemblage1.SLDASM, boitier_solaire_couv_v2.SLDPRT, boitier_solaire_couv_v2.STL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]
